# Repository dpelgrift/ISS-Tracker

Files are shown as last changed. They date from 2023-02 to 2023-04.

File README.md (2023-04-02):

# ISS-Tracker
Assembly instructions available here: https://www.printables.com/model/383268-iss-tracker

The electronics here are based around an Adafruit Feather m0 Express with a Featherwing ESP32 Wifi coprocessor. In order to build with the arduino IDE, you'll need to install Adafruit boards and SAMD support. Follow the guide here: https://learn.adafruit.com/adafruit-feather-m0-express-designed-for-circuit-python-circuitpython/arduino-ide-setup

In addition to the other dependencies, which can be installed with the standard Arduino IDE library manager, the Airlift Featherwing uses an Adafruit fork of the WiFiNINA library. See here for additional details: https://learn.adafruit.com/adafruit-airlift-featherwing-esp32-wifi-co-processor-featherwing/arduino

## Configuration
You'll need to make some minor modifications before getting up and running. The biggest ones are found in arduino_secrets.h, where you'll need to fill in your wifi SSID and password so that it can actually connect to the internet, and your precise latitude & longitude so that it can perform proper pointing. If you end up forking this code, make absolutely sure not to push any commits with these fields filled in.

Aside from that, all other configuration parameters can be found in defs.h. They should all hopefully be pretty self-explanatory. If you are omitting the compass, make sure you set DO_BYPASS_COMPASS to true. Also be sure to set your timeZone properly so that the displayed time is correct. Finally, you may need to adjust the SERVO_MIN_PWM and SERVO_MAX_PWM parameters so that the pointer properly points with the correct elevation. On startup, the servo will run through a test cycle, attempting to point at 0 degrees, then -90, then +90, then back to 0. This should give you a chance to make sure that the PWM range specified by these parameters is correct. If it isn't, double-check the spec sheet for your micro-servo of choice.

## Notes on electical connections
A simple schematic is included under Schematic.png. Note that the compass and OLED Featherwing are both connected using 4-wire stemma QT cables. Note also that the Wifi featherwing is not included in the schematic as it just stacks directly on top of the Feather M0 using stacking headers. In my build I used a perma-proto board to handle both distribution of power and breaking out the I2C clock and data signals to both the compass and display.

## Dependencies:
Adafruit GFX Library

Adafruit SH110X

Adafruit MMC56x3

AccelStepper

TimeLib

WiFiNINA (Adafruit fork, see above)

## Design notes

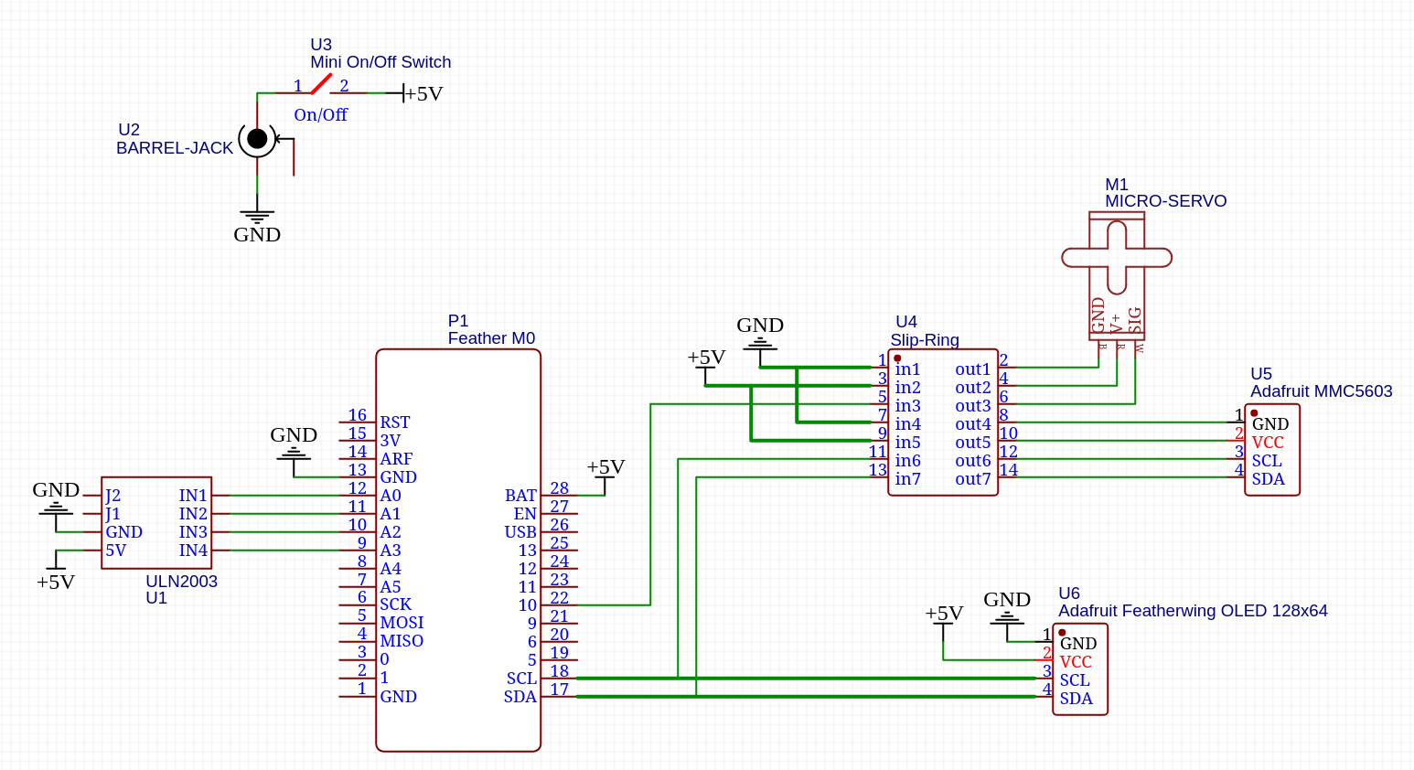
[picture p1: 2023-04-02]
Schematic.png

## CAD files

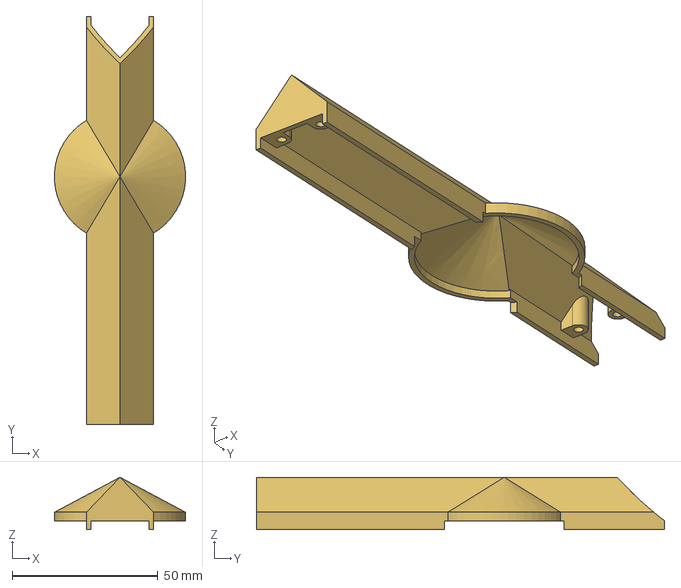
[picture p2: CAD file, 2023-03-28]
CAD/STEP/WireCover.step
44.9 x 140.0 x 18.0 mm

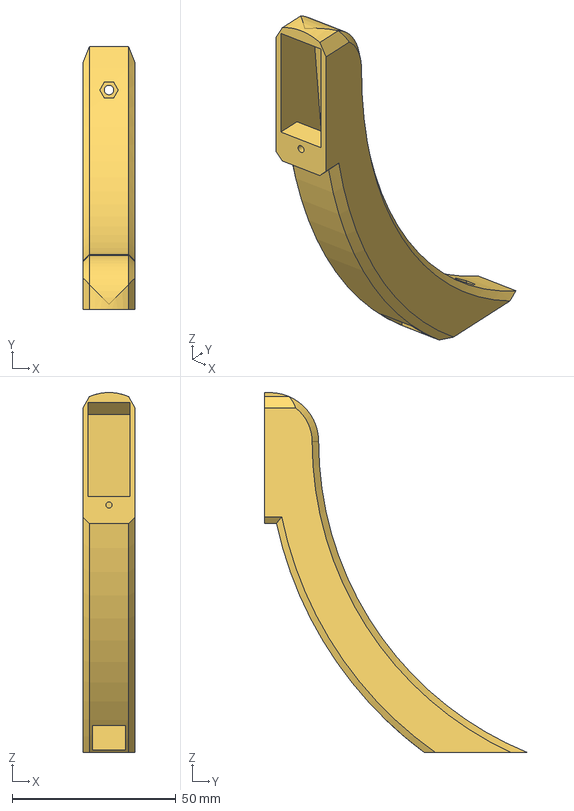
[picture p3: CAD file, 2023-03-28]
CAD/STEP/RearSupport.step
16.0 x 80.3 x 110.0 mm

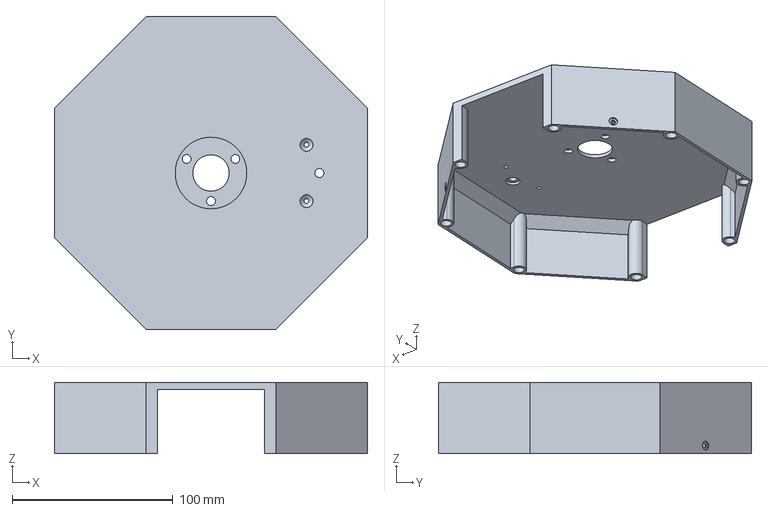
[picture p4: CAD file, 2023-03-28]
CAD/STEP/StandTop.step
195.0 x 195.0 x 44.4 mm

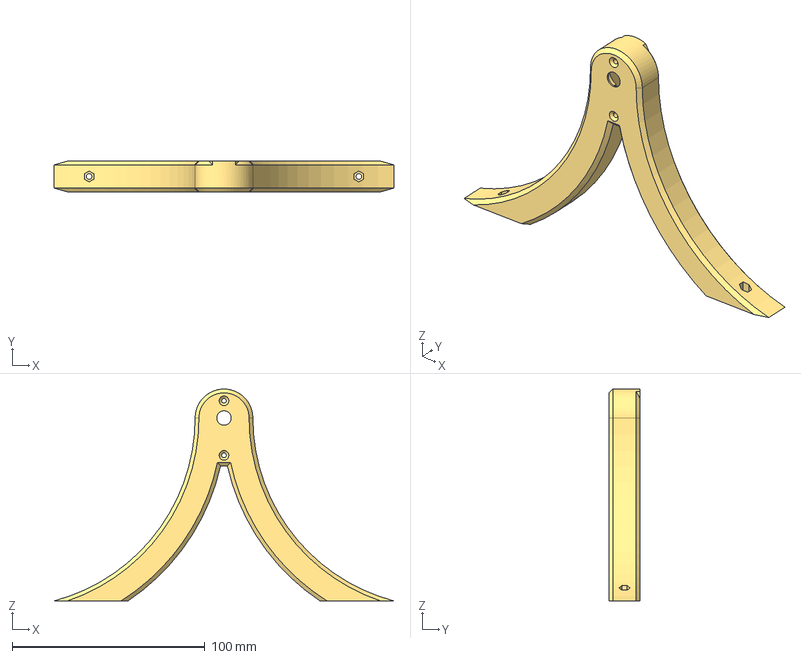
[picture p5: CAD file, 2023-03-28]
CAD/STEP/Upright.step
176.5 x 16.0 x 110.0 mm

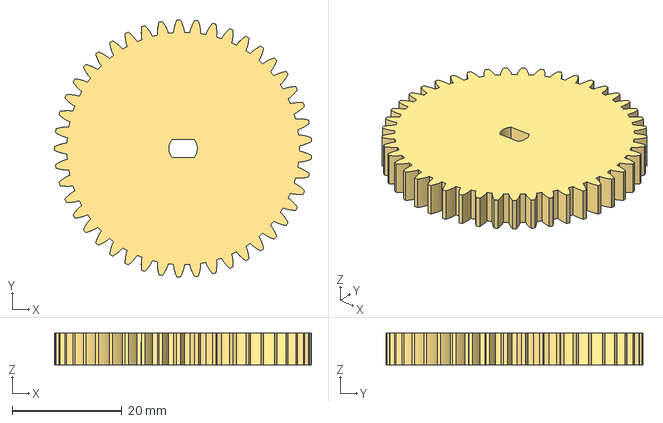
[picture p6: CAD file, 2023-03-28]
CAD/STEP/PlanetGear.step
46.8 x 46.9 x 5.80 mm

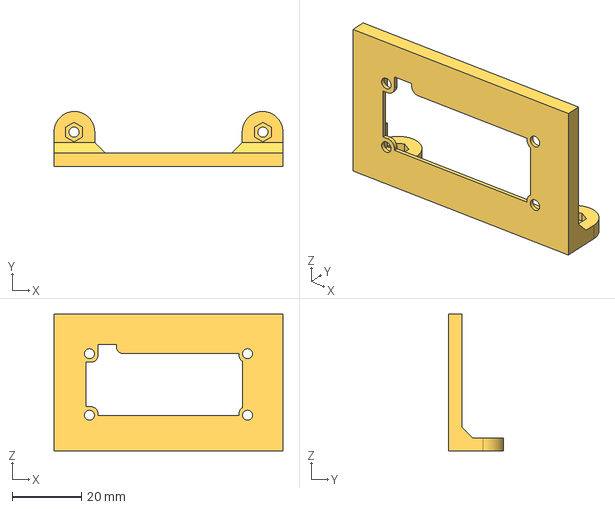
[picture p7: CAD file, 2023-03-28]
CAD/STEP/FrontPanel.step
66.2 x 16.0 x 39.6 mm

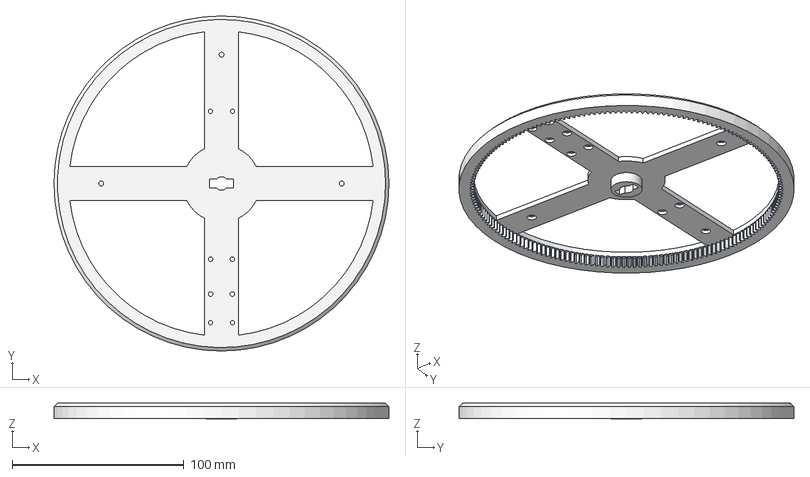
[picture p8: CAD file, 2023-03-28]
CAD/STEP/RingGear.step
195.0 x 195.0 x 9.10 mm

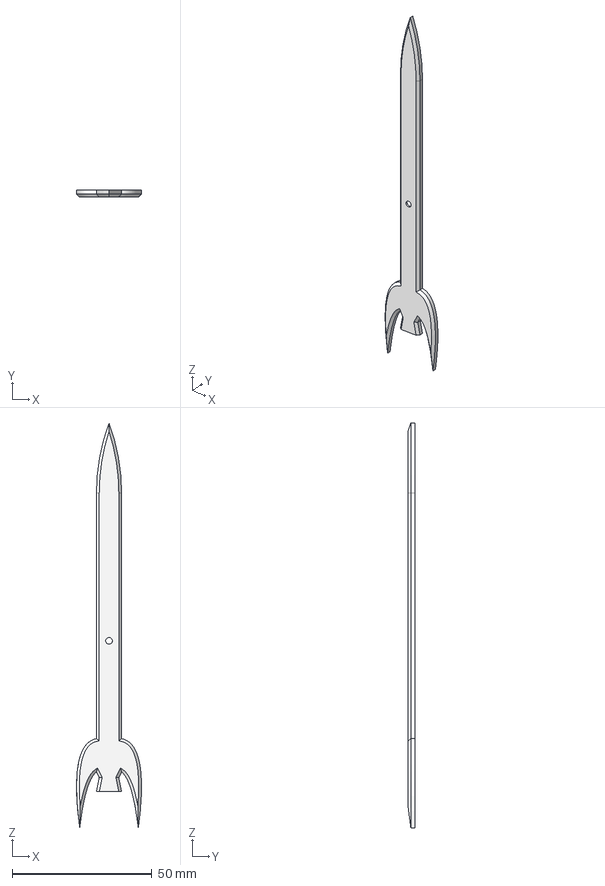
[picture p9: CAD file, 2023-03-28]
CAD/STEP/Pointer.step
23.3 x 2.50 x 145.0 mm

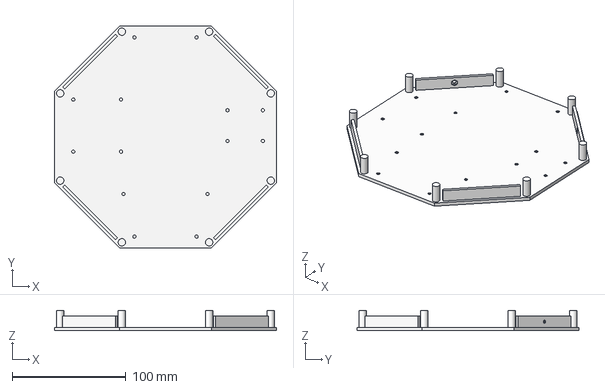
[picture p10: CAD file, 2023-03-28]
CAD/STEP/StandBottom.step
195.0 x 195.0 x 18.0 mm

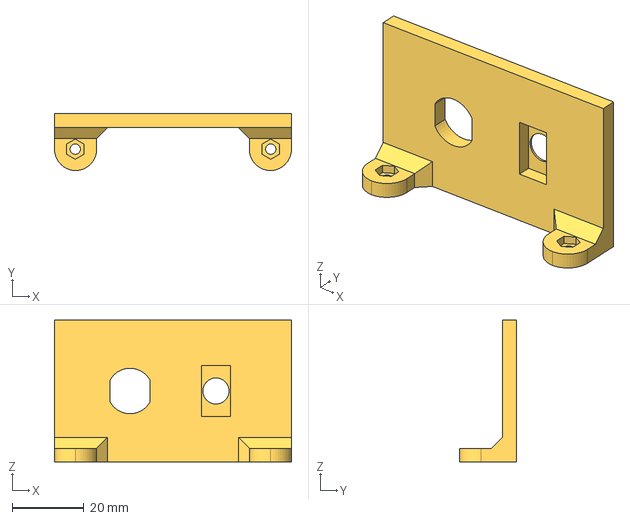
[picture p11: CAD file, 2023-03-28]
CAD/STEP/RearPanel.step
66.2 x 16.0 x 39.6 mm

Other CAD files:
CAD/FrontPanel.stl
CAD/PlanetGear.stl
CAD/Pointer.stl
CAD/RearPanel.stl
CAD/RearSupport.stl
CAD/RingGear.stl
CAD/StandBottom.stl
CAD/StandTop.stl
CAD/Upright.stl
CAD/WireCover.stl

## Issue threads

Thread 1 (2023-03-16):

possible improvements related to rotational platform

dlarue, 2023-03-16:
Great project and nice implementation.  I was looking at it and noticed the compass is moving on the plate when it could be mounted on the base and have a pin on the rotating plate which will push a switch or a hall effect switch or even a little photo diode sensor board to know where the rotating plate start position is.  By doing this you removed all the wires of the compass and only have 3 wires for the servo so maybe a simple stereo 1/8" audio jack could be used as a slip joint for the 3 wires the servo needs.

These would allow the geared plate to rotate without worry of wires getting twisted too much or having to backup to unwind.

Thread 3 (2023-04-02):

Hardcoded NIST IP should be removed

MDSchechtman, 2023-04-02:
Using `129.6.15.28` directly as the timeserver produces inconsistent results after restarts. The first request over a given period of time will succeed but subsequent requests will never return until some timeout is reached.

As per https://tf.nist.gov/tf-cgi/servers.cgi:

> Whether you connect to a server using the name or the IP address, it is a bad practice to “hard-code” a particular server name or address into a device so that these parameters cannot be changed by the end user if that becomes necessary at some future time.

> All users should ensure that their software NEVER queries a server more frequently than once every 4 seconds. Systems that exceed this rate will be refused service. In extreme cases, systems that exceed this limit may be considered as attempting a denial-of-service attack.

Oddly enough, I can produce this state by just power cycling once or twice.

The recommendation is to use `time.nist.gov`, so:

```
Udp.beginPacket("time.nist.gov", 123)
```

Which works fine for me.

dpelgrift, 2023-04-02:
Thanks for letting me know. I've pushed an update to query time.nist.gov directly

Closed 2023-04-02.

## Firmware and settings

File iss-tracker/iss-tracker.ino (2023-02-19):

/*
  iss-tracker.ino - Main methods
 */

#include <Arduino.h>
#include <string.h>
#include <SPI.h>
#include <Wire.h>
#include "arduino_secrets.h"
#include "coord.h"
#include "orbit_utils.h"
#include "wifi_utils.h"
#include "display_utils.h"
#include "pedestal.h"

#include "defs.h"

// Make sure to enter the appropriate info in arduino_secrets.h
char ssid[] = SECRET_SSID;    // network SSID
char pass[] = SECRET_PASS;    // network password (use for WPA, or use as key for WEP)
Vec3 llaRef = {SECRET_LAT,SECRET_LON,0}; // Pedestal Lat/Lon


// Wrapper Structs
NtpQueryHandler ntp{};
TleQueryHandler tle{};
Pedestal ped{};
Orbit orb{};

// Misc. variable declaration
Vec3 posECI, velECI, posECEF, posLLA, posNED, posAER;
double era;
int wifiStatus = WL_IDLE_STATUS;
uint32_t lastTleUpdateMillis, lastOrbitUpdateMillis, lastNtpUpdateMillis;

bool ntpPacketSent = false;
bool tleQuerySent = false;

void setup() {
    // Initialize serial and wait for port to open
    Serial.begin(9600);
    delay(250);
    while (!Serial && WAIT_FOR_SERIAL) {}

    /* Initialise the display */
    delay(250); // wait for the OLED to power up
    if (!display.begin(0x3C, true)) {  // Address 0x3C default
      Serial.println("No display detected");
      while (CHECK_DISPLAY_CONNECTION) delay(10);
    }

    // Show image buffer on the display hardware.
    // Since the buffer is intialized with an Adafruit splashscreen
    // internally, this will display the splashscreen.
    display.display();
    delay(1000);
    display.setRotation(1);
    resetDisplay(0,0,1);

    // Initialize pedestal wrapper
    ped.begin();

    // Test pointer elevation range
    // Should point at 0 degrees, then -90, then +90, then back to 0
    // If any are significantly misaligned from expectation,
    // then you'll need to adjust the SERVO_MIN_PWM & SERVO_MAX_PWM
    // params in defs.h. Check the spec sheet for your micro-servo of choice
    ped.setElevation(90);
    delay(1000);
    ped.servo.writeMicroseconds(SERVO_MIN_PWM);
    delay(1000);
    ped.servo.writeMicroseconds(SERVO_MAX_PWM);
    delay(1000);
    ped.setElevation(90);

    // If using the compass to align northward, perform a few attempts at automatically pointing northward
    if (!DO_BYPASS_COMPASS) {
        for (int i = 0; i < 3; ++i){
            resetDisplay(0,0,2);
            display.printf("Az: %0.1f\n",ped.getAverageHeading());
            display.display();
            ped.pointNorth();
        }
        resetDisplay(0,0,2);
        display.printf("Az: %0.1f\n",ped.getAverageHeading());
        display.display();
        delay(100);
    }
    

    // Reset stepper step count to zero to establish current step count as zero azimuth
    ped.stepper.setCurrentPosition(0);
    
    // check for the WiFi module:
    WiFi.setPins(SPIWIFI_SS, SPIWIFI_ACK, ESP32_RESETN, ESP32_GPIO0, &SPIWIFI);
    while (WiFi.status() == WL_NO_MODULE) {
        Serial.println("Communication with WiFi module failed!");
        resetDisplay(0,0,1);
        display.println("Communication with WiFi module failed!");
        display.display();
        // don't continue
        while (true) {}
    }

    // Check Wifi Co-processor Firmware
    String fv = WiFi.firmwareVersion();
    Serial.print("Found firmware "); Serial.println(fv);

    // List visible Wifi Networks
    Serial.println("Scanning available networks...");
    listNetworks();

    // Attempt to connect to Wifi network:
    resetDisplay(0,10,1);
    Serial.print("Attempting to connect to SSID: ");
    Serial.println(ssid);
    display.print("Attempting to connect to SSID:\n");
    display.println(ssid);
    display.display();

    // Connect to WPA/WPA2 network
    do {
        wifiStatus = WiFi.begin(ssid, pass);
        delay(10000);     // wait until connection is ready!
    } while (wifiStatus != WL_CONNECTED);

    Serial.println("Connected to wifi");
    display.println("Connected to wifi");
    display.display();
    delay(1000);

    // Start NTP connection
    ntp.begin();
    Serial.println("\nStarting connection to NTP server...");
    display.println("\nStarting connection to NTP server...");
    display.display();
    delay(100);

    // Get unix time
    ntp.sendNTPpacket(); // send an NTP packet to the time server
    // wait to see if a reply is available
    while (!ntp.parsePacket()) {};
    displayCurrTime(0.0,0.0);

    // Send initial TLE query
    tle.sendQuery();

    // Wait for response
    while (!tle.rcvData()){}
    tle.readTLE();

    Serial.println(tle.line1);
    Serial.println(tle.line2);

    // Parse received TLE
    tle.getOrbit(orb);

    if (DO_PRINT_DEBUG) {
        Serial.println();
        Serial.print("epoch: "); Serial.println(orb.epoch_J);
        Serial.print("utc:   "); Serial.println(orb.epochUTC);
        Serial.print("incl:  "); Serial.println(orb.incl,8);
        Serial.print("a:     "); Serial.println(orb.a);
        Serial.print("ecc:   "); Serial.println(orb.ecc,8);
        Serial.print("Omega: "); Serial.println(orb.Omega,8);
        Serial.print("omega: "); Serial.println(orb.omega,8);
        Serial.print("M0:    "); Serial.println(orb.M0,8);
        Serial.print("n:     "); Serial.println(orb.n,8);
        Serial.print("n_dot: "); Serial.println(orb.n_dot,16);
    }
    
    // Initialize timers
    lastNtpUpdateMillis   = millis();
    lastTleUpdateMillis   = lastNtpUpdateMillis;
    lastOrbitUpdateMillis = lastNtpUpdateMillis;
    delay(100);

    if (DO_PRINT_DEBUG) {
        Serial.print("In setup(): lastNtpUpdateMillis: ");
        Serial.println(int32_t(lastTleUpdateMillis));
        Serial.print("In setup(): lastTleUpdateMillis: ");
        Serial.println(int32_t(lastTleUpdateMillis));
    }
}

uint32_t currMillis, timeSinceNtpUpdate_ms, timeSinceTleUpdate_ms, timeSinceOrbitUpdate_ms;

void loop() {
    // Get current time
    currMillis = millis();

    // Try to catch overflow of millis() count and handle gracefully
    if (currMillis < lastNtpUpdateMillis) {
        lastNtpUpdateMillis = currMillis;
        lastTleUpdateMillis = currMillis;
        lastOrbitUpdateMillis = currMillis;

        Serial.println("Time counter overflow hit");
    }

    timeSinceNtpUpdate_ms = (currMillis - lastNtpUpdateMillis);
    timeSinceTleUpdate_ms = (currMillis - lastTleUpdateMillis);
    timeSinceOrbitUpdate_ms = (currMillis - lastOrbitUpdateMillis);

    // Advance stepper if necessary
    ped.runStepper();

    // Recheck wifi connection status, and try to reconnect if disconnected
    if (WiFi.status() != WL_CONNECTED) {
        resetDisplay(0,0,1);
        display.println("Wifi disconnected, attempting to reconnect...");
        display.display();
        do {
            wifiStatus = WiFi.begin(ssid, pass);
            delay(10000);     // wait until connection is ready!
        } while (wifiStatus != WL_CONNECTED);
    }

    // Resend NTP packet regularly to keep time synchronized
    if (!ntpPacketSent && (timeSinceNtpUpdate_ms > (TIME_REFRESH_DELAY_MIN*60*1000))) {
        ntp.sendNTPpacket();
        ntpPacketSent = true;
        Serial.println("NTP Packet Sent");
    } else {
        if (ntp.parsePacket()) {
            Serial.println("Parsed NTP Packet");
            lastNtpUpdateMillis = millis();
            ntpPacketSent = false;
        }
    }

    // Resend TLE Query regularly to get updated ephemeris
    if (!tleQuerySent && (timeSinceTleUpdate_ms > (TLE_REFRESH_DELAY_MIN * 60*1000))) {
        tle.sendQuery();
        tleQuerySent = true;
        Serial.println("TLE Query Sent");
    } else if (tleQuerySent) {
        if (tle.rcvData()) {
            Serial.println("Updating Ephemeris");
            tle.readTLE(); // Read received TLE data into separate lines
            tle.getOrbit(orb); // Update orbit from received TLE data
            lastTleUpdateMillis = millis();
            tleQuerySent = false;
        }
    }

    uint64_t currUTC_ms = uint64_t(ntp.unixEpoch)*1000 + uint64_t(timeSinceNtpUpdate_ms);

    // Update Az/El at regular rate
    if (timeSinceOrbitUpdate_ms >= ORBIT_REFRESH_DELAY_MS) {
        
        // Calc Earth-Rotation-Angle for current UTC
        era = getEraFromJulian(getJulianFromUnix(currUTC_ms/1000));
        
        // Calc ECI Pos/Vel for current UTC
        orb.calcPosVelECI_UTC(currUTC_ms,posECI,velECI);
        lastOrbitUpdateMillis = millis();
        posECEF = eci2ecef(posECI,-era);
        posLLA = ecef2lla(posECEF,DEGREES);
        posNED = ecef2ned(posECEF,llaRef,DEGREES);
        posAER = ned2AzElRng(posNED);

        if (DO_PRINT_DEBUG) {
            Serial.printf("System Time: %04i-%02i-%02i  %02i:%02i:%02i\n",
                        year(),month(),day(),hour(),minute(),second());
          
            Serial.printf("timeSinceNtpUpdate_ms: %lu, timeSinceTleUpdate_ms: %lu\n",
                            timeSinceNtpUpdate_ms, timeSinceTleUpdate_ms);
            Serial.print("era:   "); Serial.println(era*RAD_TO_DEG,3);
            Serial.printf("posECI:  [%0.3f,%0.3f,%0.3f]\n",posECI.x,posECI.y,posECI.z);
            Serial.printf("posECEF: [%0.3f,%0.3f,%0.3f]\n",posECEF.x,posECEF.y,posECEF.z);
            Serial.printf("posLLA:  [%0.3f,%0.3f,%0.3f]\n",posLLA.x,posLLA.y,posLLA.z/1e3);
            Serial.printf("posNED:  [%0.3f,%0.3f,%0.3f]\n",posNED.x,posNED.y,posNED.z);
            Serial.printf("posAER:  [%0.3f,%0.3f,%0.3f]\n",posAER.x,posAER.y,posAER.z);
        }

        // Update target azimuth only if reached current step target (to avoid interrupting smooth movement)
        if (ped.stepper.distanceToGo() == 0)
            ped.setTargetAz(posAER[0]);
        ped.setElevation(90+posAER[1]);

        // Display current date/time on screen
        displayCurrTime(posAER[0],posAER[1]);
    }
}

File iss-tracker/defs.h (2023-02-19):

/*
  defs.h - General parameter definitions
 */
#pragma once

// Pins
#define SPIWIFI       SPI  // The SPI port
#define SPIWIFI_SS    13   // Chip select pin
#define ESP32_RESETN  12   // Reset pin
#define SPIWIFI_ACK   11   // a.k.a BUSY or READY pin
#define ESP32_GPIO0   -1

#define SERVO_PIN 10

// Stepper pins
#define STEP1 A3
#define STEP2 A1
#define STEP3 A2
#define STEP4 A0

// TLE Server & Query Info
#define HEADER_STR  "ISS (ZARYA)"
#define TLE_LEN     69
#define MAX_BUFFER  1024
#define SERVER      "celestrak.org"
#define QUERY       "/NORAD/elements/gp.php?CATNR=25544&FORMAT=TLE"

// Misc. Flags
#define CHECK_DISPLAY_CONNECTION    false
#define CHECK_COMPASS_CONNECTION    false
#define WAIT_FOR_SERIAL             false
#define DO_PRINT_DEBUG              false

// If set true, will not attempt to automatically point north at startup
// Assumes that pedestal is manually pointed north before startup
#define DO_BYPASS_COMPASS           false

#define MAG_NORTH_LAT           86.494
#define MAG_NORTH_LON           162.867
#define TRUE_NORTH_OFFSET_DEG   -3.73

// Refresh durations
#define TIME_REFRESH_DELAY_MIN 10
#define TLE_REFRESH_DELAY_MIN  60
#define ORBIT_REFRESH_DELAY_MS 500

// Stepper Motor Specs
#define STEPS_PER_REV (2038*4)
#define STEPPER_SPEED 500
#define STEPPER_ACCEL 300

// Servo PWM Range
#define SERVO_MIN_PWM 500
#define SERVO_MAX_PWM 2500

// Timezone used for time display
// const int timeZone = 1;   // Central European Time
const int timeZone = -5;  // Eastern Standard Time (USA)
// const int timeZone = -4;  // Eastern Daylight Time (USA)
// const int timeZone = -8;  // Pacific Standard Time (USA)
// const int timeZone = -7;  // Pacific Daylight Time (USA)

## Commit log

2022-12-07 Added startup print statements to print to OLED display
2022-12-20 Added bearing calculation function
2022-12-20 Added magnetic north lat/lon and magnetic event to main.cpp
2022-12-23 Multiple fixes. Now tracking azimuth correctly
    [defs.h, pedestal.cpp, wifi_utils.cpp]
2023-01-18 Updated servo elevation & compass heading
2023-01-29 Misc. fixes and updates
    [defs.h, pedestal.cpp]
2023-02-19 Moved files into arduino sketch format
2023-02-19 Fixed formatting issues with conversion to arduino sketch
    [iss-tracker.ino, wifi_utils.cpp]
2023-02-19 Updated timers to use milliseconds instead of seconds. Misc other fixes
    [defs.h, iss-tracker.ino]
2023-03-06 Removed old vscode files. Added .stl model files
    [FrontPanel.stl, PlanetGear.stl, Pointer.stl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]
2023-03-28 Added .step versions of model files
    [FrontPanel.step, PlanetGear.step, Pointer.step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]
2023-04-02 Replaced static timeserver IP with "time.nist.gov"
    [wifi_utils.cpp]
2023-04-02 Added electrical schematic
